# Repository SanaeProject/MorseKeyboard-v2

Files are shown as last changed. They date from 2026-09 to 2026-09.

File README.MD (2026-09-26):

# MorseKeyboard-V2

このリポジトリではモールス信号を用いて、キーボード入力、[LoRA](https://ja.wikipedia.org/wiki/LoRa)通信を行うことができるシステムを開発しています。

## 概要

- Bluetoothを用いたキーボード入力
- [LoRA](https://ja.wikipedia.org/wiki/LoRa)通信を用いた機器同士の通信

> [!WARNING]
> LoRA通信を行う場合は、[LoRA](https://ja.wikipedia.org/wiki/LoRa)の周波数帯域に注意してください。
> 日本では、920MHz帯を使用する必要があります。
> また、技適マークのないLoRAモジュールを使用する場合は、電波法違反となる可能性がありますので、注意してください。

### Bluetoothキーボード入力

モールス信号を用いて、Bluetoothキーボードとして動作することができます。  
これにより、モールス信号を入力することで、文字を打つことができます。

### LoRA通信

モールス信号を用いて、[LoRA](https://ja.wikipedia.org/wiki/LoRa)通信を行うことができます。
**このプロジェクトで作成した`E220`ヘッダは日本版のモジュールのみ対応しています。**

### 材料

- [ESP32C6](https://akizukidenshi.com/catalog/g/g129481/) 1100円
- [E220-900T22S](https://akizukidenshi.com/catalog/g/g131361/) (日本版) 1980円
- [ユニバーサル基板](https://akizukidenshi.com/catalog/g/g103229/) 130円
- [OLEDディスプレイ](https://www.amazon.co.jp/dp/B0GTV26DD2?ref=ppx_yo2ov_dt_b_fed_asin_title) 580円
- [800mAh Li-ionバッテリ](https://www.amazon.co.jp/dp/B0GTV26DD2?ref=ppx_yo2ov_dt_b_fed_asin_title) 990円
- アンテナ(920MHz) お好みでどおぞ

そのほか、ジャンパーワイヤやスイッチ、10kΩ抵抗、はんだ付け用の道具などが必要です。

### 配線

#### 表面

> [!NOTE]
> それぞれで配線を考えることをお勧めします。
> この配線では、Analogピンをすべて使用しているため、バッテリー電圧を測定できません。
> また、`esp32c6`の`GPIO 0`は、起動時にLOWにするとブートモードに入るため、LOWにしないように注意してください。

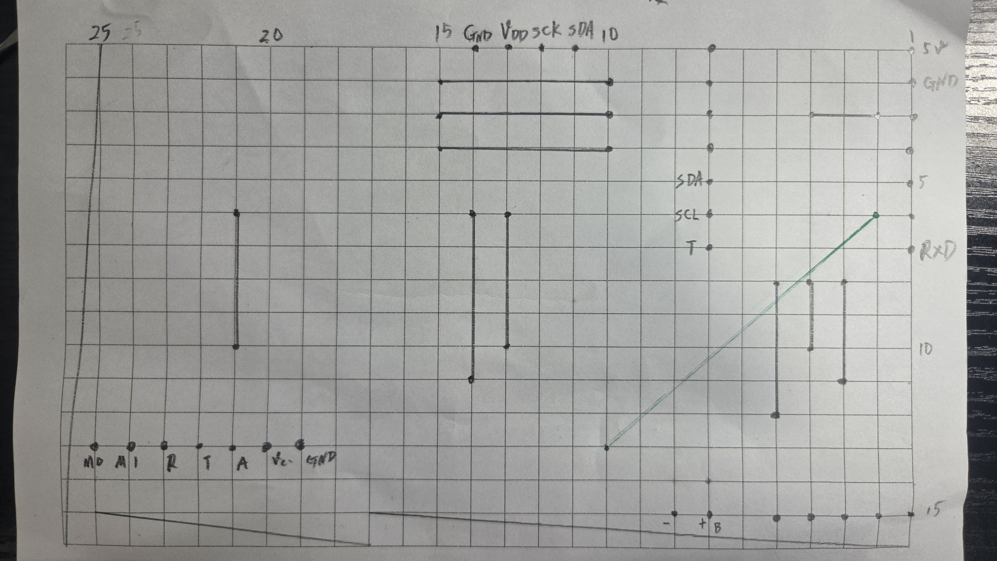
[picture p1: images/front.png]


### 裏面

> [!NOTE]
> 裏面の配線にて5vではなく3.3vを使用する必要があります。
> 5vを使用すると、バッテリー駆動時に5vが供給されず正常に動作しません。

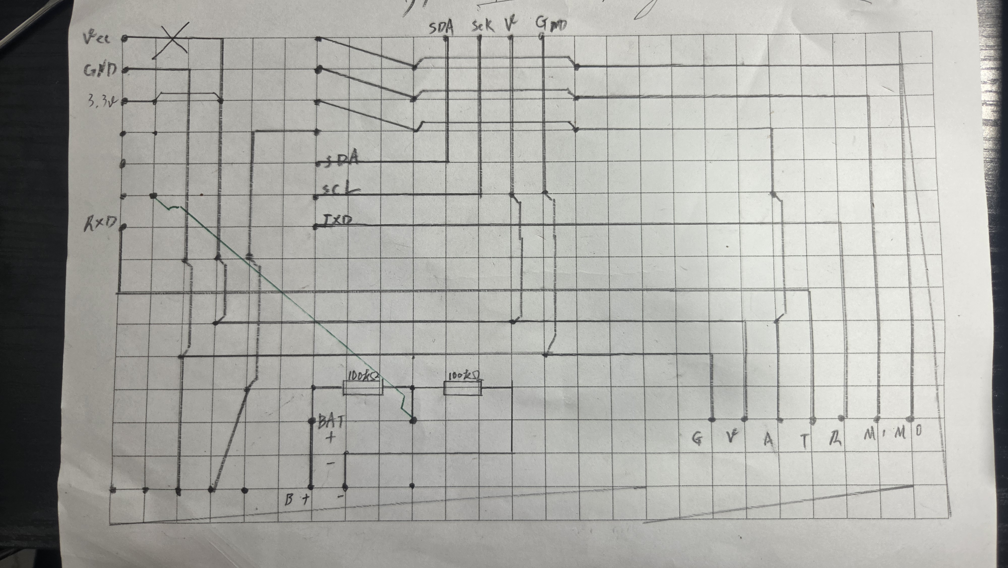
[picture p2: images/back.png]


### ケース

3Dプリンタでケースを作成することができます。  
STLファイルは[こちら](body.stl)にあります。

### 完成図

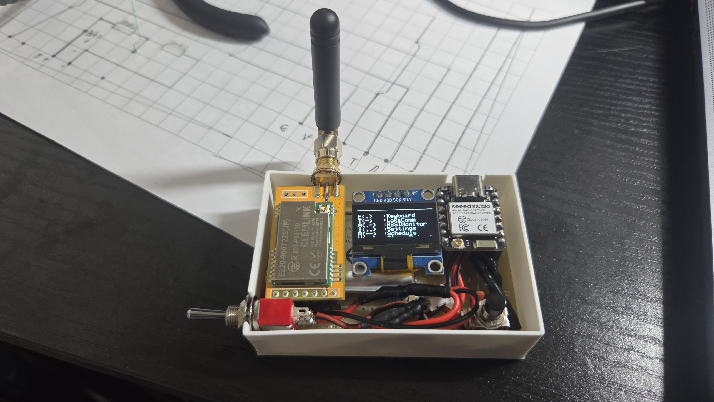
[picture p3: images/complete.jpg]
完成図


### 対応しているモールス信号

以下は、このシステムで対応しているモールス信号の一覧です。  
[Morse.hpp](include/Morse.hpp)に定義されているモールス信号を参照しています。

|文字|モールス信号|
|---|---|
|A|・－|
|B|ー・・・|
|C|－・－・|
|D|－・・|
|E|・|
|F|・・－・|
|G|－－・|
|H|・・・・|
|I|・・|
|J|・ーー|
|K|－・ー|
|L|・－・・|
|M|－－|
|N|－・|
|O|－－－|
|P|・－－・|
|Q|－－・ー|
|R|・－・|
|S|・・・|
|T|ー|
|U|・・ー|
|V|・・・ー|
|W|・－－|
|X|ー・・ー|
|Y|ー・ーー|
|Z|ーー・・|
|0|ーーーーー|
|1|・ーーーー|
|2|・・ーーー|
|3|・・・ーー|
|4|・・・・ー|
|5|・・・・・|
|6|ー・・・・|
|7|ーー・・・|
|8|ーーー・・|
|9|ーーーー・|
|\n|・・・ー・－|
|\e|・－・－・|
|\b|・・・・・・・・|

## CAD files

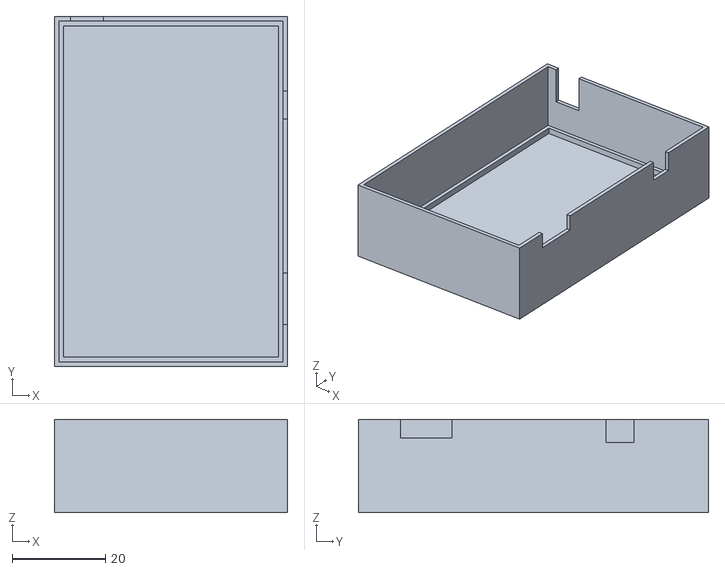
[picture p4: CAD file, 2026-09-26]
body.stl
50.0 x 75.0 x 20.0

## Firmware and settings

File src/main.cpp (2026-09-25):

#include <Arduino.h>
#include "Morse.hpp"
#include "OledDisplay.hpp"
#include "E220.hpp"
#include <Wire.h>
#include <Adafruit_GFX.h>
#include <Adafruit_SSD1306.h>
#include <HijelHID_BLEKeyboard.h>

#define ERROR(code) while(1){code; delay(1000);}
// I2C OLED display settings
#define OLED_RESET      -1
#define SCREEN_WIDTH    128
#define SCREEN_HEIGHT   64
#define LCD_I2C_ADDRESS 0x3c
#define I2C_SDA_PIN     22
#define I2C_SCL_PIN     23

// E220 module pin settings
#define M0_PIN   0
#define M1_PIN   1
#define AUX_PIN  2
#define TX_PIN   16
#define RX_PIN   17

// Morse
#define SIGNAL_PIN      21

// Battery
#define BATTERY_PIN     19

// 動作モード
enum class AppMode {
    MAIN_MENU,
    MORSE_KEYBOARD,
    LORA_COMMUNICATION,
    SETTINGS,
    RSSI_MONITOR,
    SCHEDULE,
};

//SECTION Global Variables
AppMode currentMode = AppMode::MAIN_MENU; // default

E220                  e220;
MorseSignalReader     morse;
HijelHID_BLEKeyboard  keyboard("MorseKeyboard", "SanaeProject", 100);
Adafruit_SSD1306      display(SCREEN_WIDTH, SCREEN_HEIGHT, &Wire, OLED_RESET);
OledDisplay           oledDisplay(display, 1, SSD1306Color::White, Align::Left);

// Settings
uint16_t tempAddress = 0;
uint8_t  tempChannel = 0;
uint16_t tempTargetAddress = 0;
uint16_t tempCryptKey = 0;

enum class SettingsItem {
    ADDRESS,
    CHANNEL,
    SEND_MODE,
    TARGET_ADDRESS,
    CRYPT_KEY
};

SettingsItem settingsItem = SettingsItem::ADDRESS;
String settingsInput = "";

// Lora
constexpr uint8_t MAX_MESSAGE_ROWS = 3;
uint8_t receivedMessageRow = 0;
uint8_t receivedMessageCol = 0;
String receivedMessage = "";

uint8_t sentMessageRow = 0;
uint8_t sentMessageCol = 0;
String sentMessage = "";

// RSSI Noise Monitor
constexpr size_t GRAPH_LENGTH = 5;
constexpr size_t GRAPH_REFRESH = 1000; // 1秒ごとに更新
int16_t noises[GRAPH_LENGTH];
size_t lastIdx = GRAPH_LENGTH-1;
Timer rssiTimer;

// Schedule
String scheduleMessage = "";
Timer scheduleTimer;
uint8_t scheduleCnt = 0;

//!SECTION

//SECTION プロトタイプ宣言
void mainMenu();          //ANCHOR - Main Menu
void loraCommunication(); //ANCHOR - LoRa Communication
void morseKeyboard();     //ANCHOR - Morse Keyboard
void rssiMonitor();       //ANCHOR - RSSI Noise Monitor
void settings();          //ANCHOR - Settings
void schedule();          //ANCHOR - Schedule
//!SECTION

//SECTION entry
//ANCHOR Setup
void setup(){
    // シリアル通信の初期化
    Serial.begin(115200);

    // キーボード初期化
    keyboard.begin();

    // ディスプレイの初期化
    if(display.begin(SSD1306_SWITCHCAPVCC, LCD_I2C_ADDRESS))
        Serial.println("SSD1306 allocated successfully!");
    else
        ERROR(Serial.println("SSD1306 allocation failed"));
    oledDisplay.init();
    oledDisplay.clear();

    // E220モジュールの初期化
    e220.setLogLevel(E220_LogLevel::INFO);
    if (!e220.begin(&Serial1, RX_PIN, TX_PIN, M0_PIN, M1_PIN, AUX_PIN, &Serial))
        ERROR(Serial.println("E220 begin failed"));
    if(!e220.readConfig())
        ERROR(Serial.println("E220 Failed to config read."));
    
    // 前回の引継ぎ
    tempAddress = e220.getDeviceAddress();
    tempChannel = e220.getFrequencyChannel();
    tempTargetAddress = tempAddress;
    tempCryptKey = e220.getCryptKey();

    const bool written = e220.setDeviceAddress(tempAddress)
        .setUARTSerialPortRate(E220_UARTSerialPortRate::RATE_9600)
        .setAirDataRate(E220_AirDataRate::BW125_1758BPS)
        .setPayloadLength(E220_PayloadLength::LENGTH_200)
        .setRSSINoiseEnable(true)
        .setTxPower(E220_TxPower_22S::POWER_13DBM)
        .setFrequencyChannel(tempChannel)
        .setRSSIByteEnable(false)
        .setSendMode(E220_SendMode::MODE_TRANSPARENT)
        .setWORCycle(E220_WORCycle::CYCLE_500MS)
        .setCryptKey(tempCryptKey)
        .writeConfig();
    if (!written)
        ERROR(Serial.println("E220 Failed to config write."));

    // Morse
    morse.begin(SIGNAL_PIN);

    // 完了画面
    Serial.println("===========Setup complete===========");
    oledDisplay.setTextSize(1);
    oledDisplay.setAlign(Align::Center)
        .clear()
        .setCursor(0, oledDisplay.getHeight() / 2)
        .println("Morse Keyboard v2")
        .setAlign(Align::Right)
        .println("by SanaeProject")
        .nextLine()
        .setAlign(Align::Left)
        .println("Author: SanaeProject")
        .println("Version: 1.0.0");
        
    delay(2000);
    oledDisplay.clear();
    pinMode(BATTERY_PIN, INPUT);
}

// ANCHOR Loop
bool isPressed = false;
void loop(){
    bool pressed = digitalRead(SIGNAL_PIN) == LOW;
    if(pressed && !isPressed){
        Serial.println("Button pressed");
        isPressed = true;
    } else if(!pressed && isPressed){
        Serial.println("Button released");
        isPressed = false;
    }

    switch(currentMode){
    case AppMode::MAIN_MENU:
        mainMenu();
        break;
    case AppMode::LORA_COMMUNICATION:
        loraCommunication();
        break;
    case AppMode::MORSE_KEYBOARD:
        morseKeyboard();
        break;
    case AppMode::RSSI_MONITOR:
        rssiMonitor();
        break;
    case AppMode::SETTINGS:
        settings();
        break;
    case AppMode::SCHEDULE:
        schedule();
        break;
    }

    delay(2);
}
//!SECTION

//SECTION pages
//ANCHOR - Main Menu
void mainMenu(){
    // setup
    oledDisplay.setTextSize(1)
        .setCursor(0, 0)
        .setAlign(Align::Center)
        .println("Morse Keyboard")
        .drawRect(0, oledDisplay.getCursorY(), oledDisplay.getWidth(), 1, SSD1306Color::White);

    // content
    oledDisplay.nextLine()
        .setAlign(Align::Left)
        .println("E(.)   :Keyboard")
        .println("T(-)   :LoRaComm")
        .println("A(.-)  :RSSIMonitor")
        .println("I(..)  :Settings")
        .println("M(--)  :Schedule")
        .println("N(-.)  :Clear Paired");

    char key = morse.getKey();
    AppMode previousMode = currentMode;
    switch(key){
    case 'e':
        currentMode = AppMode::MORSE_KEYBOARD;
        break;
    case 't':
        currentMode = AppMode::LORA_COMMUNICATION;
        break;
    case 'a':
        currentMode = AppMode::RSSI_MONITOR;
        break;
    case 'i':
        currentMode = AppMode::SETTINGS;
        break;
    case 'm':
        currentMode = AppMode::SCHEDULE;
        break;
    case 'n':
        keyboard.clearBonds();
        oledDisplay.clear()
            .setAlign(Align::Center)
            .setCursor(0, oledDisplay.getHeight() / 2 - BASE_CHAR_HEIGHT)
            .println("Cleared paired devices");
        delay(2000);
        oledDisplay.clear();

        currentMode = AppMode::MAIN_MENU;
        break;
    case MORSE_KEY_NONE:
        break;
    default:
        Serial.print("Invalid input: " + String(key));
        oledDisplay.setAlign(Align::Center)
            .clearLine()
            .print("Invalid input: " + String(key));

        break;
    }

    if(previousMode != currentMode)
        oledDisplay.clear();
}

// ANCHOR - LoRa Communication
void loraInsertBuffer(const char c, String& message, uint8_t& row, uint8_t& col){
    if(c == '\r') return; // 改行コードは無視

    message += c;
    col++;
    uint16_t width = (col + 1) * BASE_CHAR_WIDTH + oledDisplay.getPadding().left;
    bool isLineBreak = (c == '\n') || (width >= oledDisplay.getWidth());

    if(width >= oledDisplay.getWidth()){
        col = 0;
        message += '\n';
    }
    if(isLineBreak) row++;

    if(row >= MAX_MESSAGE_ROWS){ // 行数超過時に最古の1行を削除
        int firstNewline = message.indexOf('\n');
        if(firstNewline != -1)
            message = message.substring(firstNewline + 1);
        
        row--;
        oledDisplay.clear();
    }
}
void loraCommunication() {
    // 描画準備
    oledDisplay.setTextSize(1)
        .setCursor(0, 0);
    
    oledDisplay.setAlign(Align::Left)
        .println("Send:\n" + sentMessage)
        .setCursor(0, oledDisplay.getHeight() / 2)
        .fillRect(0, oledDisplay.getCursorY(), oledDisplay.getWidth(), oledDisplay.getHeight() / 2, SSD1306Color::Black)
        .drawRect(0, oledDisplay.getCursorY(), oledDisplay.getWidth(), 1, SSD1306Color::White)
        .println("Received:\n" + receivedMessage);
    oledDisplay.display();

    // 入力・送信処理
    char key = morse.getKey();
    if (key == '\e'){
        currentMode = AppMode::MAIN_MENU;
        oledDisplay.clear();
        return;
    }
    if (key != MORSE_KEY_NONE && key != '?') {
        Serial.print("Morse Key: ");
        Serial.println(key);

        if(e220.getSendMode() == E220_SendMode::MODE_TRANSPARENT)
            e220.send((uint8_t*)&key, 1);
        else
            e220.send((uint8_t*)&key, 1, tempTargetAddress,tempChannel);

        loraInsertBuffer(key, sentMessage, sentMessageRow, sentMessageCol);
    }

    // 受信データの処理
    while (e220.available()) {
        char c = e220.read();
        loraInsertBuffer(c, receivedMessage, receivedMessageRow, receivedMessageCol);
    }
}

//ANCHOR - Morse Keyboard
void morseKeyboard(){
    oledDisplay.setTextSize(1)
        .setCursor(0, 0)
        .setAlign(Align::Center)
        .println("Morse Keyboard")
        .drawRect(0, oledDisplay.getCursorY(), oledDisplay.getWidth(), 1, SSD1306Color::White)
        .nextLine();

    if(!keyboard.isConnected() || !keyboard.isPaired()){
        Serial.println("Keyboard is not connected.");
        oledDisplay.clearLine()
            .setAlign(Align::Left)
            .println("Keyboard is not connected.");
    }

    char key = morse.getKey();
    if(key == '\e'){
        currentMode = AppMode::MAIN_MENU;
        oledDisplay.clear();
        return;
    }
    if(key != MORSE_KEY_NONE){
        oledDisplay.clearLine()
            .setAlign(Align::Center)
            .println("Morse Key: " + String(key));
        keyboard.print(key);
    }
}

//ANCHOR - RSSI Monitor
size_t getFirstIdx(){
    return lastIdx+1 < GRAPH_LENGTH ? lastIdx+1 : 0;
}
size_t getNextIdx(size_t idx){
    return idx+1 < GRAPH_LENGTH ? idx+1 : 0;
}
void viewGraph(){
    const int16_t max = 0;
    const int16_t min = -110;
    const int16_t paddingX = BASE_CHAR_WIDTH * 4; // 4文字分パディング

    const int16_t x = paddingX,
    y      = oledDisplay.getHeight()/ 4,
    width  = oledDisplay.getWidth() - 2*paddingX,
    height = oledDisplay.getHeight()/ 4*3;
    
    // 初期化
    oledDisplay.setCursor(0, 0)
        .fillRect(x+1, y+1, width-2, height-2, SSD1306Color::Black);

    // 外枠
    oledDisplay.setCursor(0, y).print(String(min)) // 一番上
        .setCursor(0, y + height - BASE_CHAR_HEIGHT).print(String(max)) // 真ん中
        .setCursor(0, y+height/2 - BASE_CHAR_HEIGHT/2).print(String((max+min)/2)) // 一番下
        .drawLine(x, y+height/2, x+width, y+height/2)   // 真ん中線
        .setCursor(0, 0).drawRect(x, y, width, height); // 外枠

    const int16_t deltaGraphX = width / GRAPH_LENGTH;
    const int16_t circleRadius = 2;
    int16_t prevY = y + height/2 - (noises[lastIdx] - min) * height / (max - min);
    for(size_t cnt = 0, idx = getFirstIdx();cnt < GRAPH_LENGTH; cnt++, idx = getNextIdx(idx)){
        int16_t graphY = y + height/2 - (noises[idx] - min) * height / (max - min);
        int16_t graphX = x + cnt * deltaGraphX;

        graphY = constrain(graphY, y + circleRadius, y + height - circleRadius);
        oledDisplay.drawCircle(graphX, graphY, circleRadius);
        if(cnt > 0)
            oledDisplay.drawLine(x + (cnt-1) * deltaGraphX, prevY, graphX, graphY);
        prevY = graphY;
    }

    oledDisplay.display();
}
void rssiMonitor(){
    // エスケープ
    char key = morse.getKey();
    if(key == '\e'){
        currentMode = AppMode::MAIN_MENU;
        oledDisplay.clear();
    }

    // 1秒ごとに更新
    if(!rssiTimer.isRunning() || rssiTimer.elapsed() >= GRAPH_REFRESH){
        rssiTimer.start();
    }else
        return;

    oledDisplay.setTextSize(1)
        .setCursor(0, 0);

    int16_t rssi = e220.getRSSINoise();
    oledDisplay.clearLine()
        .setAlign(Align::Center)
        .println("RSSI: " + String(rssi) + " dBm");

    // 値を格納
    lastIdx = getFirstIdx();
    noises[lastIdx] = rssi;

    viewGraph();
}
//ANCHOR - Settings
//ANCHOR - Settings
void settings(){
    static SettingsItem item = SettingsItem::ADDRESS;
    static bool editing = false;
    static bool dirty = true; // 描画更新が必要かどうかのフラグ

    // --- 1. 入力処理 ---
    char key = morse.getKey();

    if(key != MORSE_KEY_NONE){
        dirty = true; // キー入力があったので画面を更新する

        // ESC (戻る / キャンセル)
        if(key == '\e'){
            if(editing){
                editing = false;
            }else{
                currentMode = AppMode::MAIN_MENU;
            }
            oledDisplay.clear();
            return;
        }

        // 編集中（値の変更）
        if(editing){
            switch(item){
            case SettingsItem::ADDRESS:
                if(key == 'e') { if(tempAddress < 0xFFFF) ++tempAddress; }
                else if(key == 't') { if(tempAddress > 0) --tempAddress; }
                break;

            case SettingsItem::CHANNEL:
                if(key == 'e') { if(tempChannel < 37) ++tempChannel; }
                else if(key == 't') { if(tempChannel > 0) --tempChannel; }
                break;

            case SettingsItem::SEND_MODE:
                if(key == 'e' || key == 't'){
                    if(e220.getSendMode() == E220_SendMode::MODE_TRANSPARENT)
                        e220.setSendMode(E220_SendMode::MODE_FIXED);
                    else
                        e220.setSendMode(E220_SendMode::MODE_TRANSPARENT);
                }
                break;

            case SettingsItem::TARGET_ADDRESS:
                if(key == 'e') { if(tempTargetAddress < 0xFFFF) ++tempTargetAddress; }
                else if(key == 't') { if(tempTargetAddress > 0) --tempTargetAddress; }
                break;

            case SettingsItem::CRYPT_KEY:
                if(key == 'e') { if(tempCryptKey < 0xFFFF) ++tempCryptKey; }
                else if(key == 't') { if(tempCryptKey > 0) --tempCryptKey; }
                break;
            }

            // Enter('\n')で決定
            if(key == '\n'){
                editing = false;
            }

            oledDisplay.clear();
        } 
        // 項目選択モード
        else {
            switch(key){
            case 'e': // (.) Address
                item = SettingsItem::ADDRESS;
                editing = true;
                break;

            case 't': // (-) Channel
                item = SettingsItem::CHANNEL;
                editing = true;
                break;

            case 'a': // (.-) SendMode
                item = SettingsItem::SEND_MODE;
                editing = true;
                break;

            case 'i': // (..) Target Address
                item = SettingsItem::TARGET_ADDRESS;
                editing = true;
                break;

            case 'm': // (--) Crypt Key
                item = SettingsItem::CRYPT_KEY;
                editing = true;
                break;

            case '\n': // 保存
                e220.setDeviceAddress(tempAddress)
                    .setFrequencyChannel(tempChannel)
                    .setCryptKey(tempCryptKey)
                    .writeConfig();

                oledDisplay.clear();
                break;
            }

            oledDisplay.clear();
        }
    }

    // --- 2. 描画処理（変化があった時だけ描画する） ---
    if(!dirty) return;
    dirty = false; // 描画処理を行うのでフラグを下げる

    oledDisplay.setTextSize(1)
        .setCursor(0, 0)
        .setAlign(Align::Center)
        .println("Settings")
        .drawRect(
            0,
            oledDisplay.getCursorY(),
            oledDisplay.getWidth(),
            1,
            SSD1306Color::White
        );

    oledDisplay.nextLine()
        .setAlign(Align::Left);

    if(!editing){
        oledDisplay.println("E(.)  : Address");
        oledDisplay.println("T(-)  : Channel");
        oledDisplay.println("A(.-) : SendMode");
        oledDisplay.println("I(..) : TargetAddr");
        oledDisplay.println("M(--) : CryptKey");
        oledDisplay.println("Enter : Save");
        oledDisplay.println("ESC   : Back");
    }else{
        switch(item){
        case SettingsItem::ADDRESS:
            oledDisplay.println("Address");
            oledDisplay.println("0x" + String(tempAddress, HEX));
            break;

        case SettingsItem::CHANNEL:
            oledDisplay.println("Channel");
            oledDisplay.println(String(tempChannel));
            break;

        case SettingsItem::SEND_MODE:
            oledDisplay.println("SendMode");
            oledDisplay.println(
                e220.getSendMode() == E220_SendMode::MODE_TRANSPARENT
                    ? "TRANSPARENT"
                    : "FIXED"
            );
            break;

        case SettingsItem::TARGET_ADDRESS:
            oledDisplay.println("Target Addr");
            oledDisplay.println("0x" + String(tempTargetAddress, HEX));
            break;

        case SettingsItem::CRYPT_KEY:
            oledDisplay.println("CryptKey");
            oledDisplay.println("0x" + String(tempCryptKey, HEX));
            break;
        }

        oledDisplay.println("")
            .println("E(.): UP / T(-): DOWN")
            .println("Enter: OK")
            .println("ESC: Cancel");
    }

    oledDisplay.display();
}

//ANCHOR - Schedule
void schedule() {
    oledDisplay
        .setTextSize(1)
        .setCursor(0, 0)
        .setAlign(Align::Center)
        .println("Schedule")
        .drawRect(0, oledDisplay.getCursorY(), oledDisplay.getWidth(), 1, SSD1306Color::White);

    // タイマースタート
    if (scheduleMessage.length() != 0 && !scheduleTimer.isRunning() && scheduleMessage.endsWith("\n"))
        scheduleTimer.start();

    // 送信
    if (scheduleMessage.length() != 0 && scheduleTimer.isRunning() && scheduleMessage.endsWith("\n") && scheduleTimer.elapsed() >= 5000) {

        scheduleTimer.start();
        String fullMessage = String(scheduleCnt) + "-" + scheduleMessage;

        if (e220.getSendMode() == E220_SendMode::MODE_TRANSPARENT)
            e220.send((uint8_t*)fullMessage.c_str(), fullMessage.length());
        else
            e220.send((uint8_t*)fullMessage.c_str(),fullMessage.length(),tempTargetAddress,tempChannel);

        oledDisplay.clear();
        oledDisplay
            .setTextSize(2)
            .setCursor(0, 16)
            .setAlign(Align::Center)
            .println("success!");

        oledDisplay
            .setTextSize(1)
            .setCursor(0, 42)
            .setAlign(Align::Center)
            .println(
                "Message " + String(scheduleCnt)
            );

        scheduleCnt++;

        return;
    }

    oledDisplay
        .nextLine()
        .setTextSize(1)
        .setAlign(Align::Left)
        .println("Message:");
    oledDisplay.println(scheduleMessage);

    // morse信号の入力
    char key = morse.getKey();
    if (key == '\e') {

        currentMode = AppMode::MAIN_MENU;

        oledDisplay.clear();
        scheduleTimer.stop();
        scheduleCnt = 0;
        scheduleMessage = "";

        return;
    }

    if (key != MORSE_KEY_NONE && key != '?') {

        oledDisplay
            .clearLine()
            .setAlign(Align::Center)
            .println("Morse Key: " + String(key));

        scheduleMessage += key;

        oledDisplay
            .println("Message: " + scheduleMessage);
    }
}
//!SECTION

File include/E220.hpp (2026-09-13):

/**
 * @note 参考文献: https://support.dragon-torch.tech/docs/lora/E220_ver.2.0/E220_ver.2.0_9
 */
#ifndef E220_HPP
#define E220_HPP

#include <Arduino.h>

//SECTION - 列挙型
//ANCHOR - モード
enum class E220_Mode : uint8_t {
    NORMAL = 0, // ノーマルモード
    CONFIG = 3  // コンフィグモード
};
//ANCHOR - コマンド
enum class E220_Command : uint8_t {
    WRITE_PERM = 0xC0, // 永続書き込み (EEPROM保存)
    READ       = 0xC1, // レジスタ読み出し
    ACK        = 0xC1, // E220からの応答ヘッダー
    WRITE_TEMP = 0xC2  // 一時書き込み (RAM保存)
};

//SECTION - REG0
//ANCHOR - UARTシリアル通信速度
enum class E220_UARTSerialPortRate : uint8_t {
    RATE_1200   = 0x00, // 000 1200bps
    RATE_2400   = 0x20, // 001 2400bps
    RATE_4800   = 0x40, // 010 4800bps
    RATE_9600   = 0x60, // 011 9600bps
    RATE_19200  = 0x80, // 100 19200bps
    RATE_38400  = 0xa0, // 101 38400bps
    RATE_57600  = 0xc0, // 110 57600bps
    RATE_115200 = 0xe0, // 111 115200bps
};
//ANCHOR - 空中通信速度
enum class E220_AirDataRate : uint8_t {
    // BW = 125kHz
    BW125_15625BPS = 0x00, // 00000 -> SF5,  15.625kbps
    BW125_9375BPS  = 0x04, // 00100 -> SF6,  9.375kbps
    BW125_5469BPS  = 0x08, // 01000 -> SF7,  5.469kbps
    BW125_3125BPS  = 0x0C, // 01100 -> SF8,  3.125kbps
    BW125_1758BPS  = 0x10, // 10000 -> SF9,  1.758kbps (Default)

    // BW = 250kHz
    BW250_31250BPS = 0x01, // 00001 -> SF5,  31.250kbps
    BW250_18750BPS = 0x05, // 00101 -> SF6,  18.750kbps
    BW250_10938BPS = 0x09, // 01001 -> SF7,  10.938kbps
    BW250_6250BPS  = 0x0D, // 01101 -> SF8,  6.250kbps
    BW250_3516BPS  = 0x11, // 10001 -> SF9,  3.516kbps
    BW250_1953BPS  = 0x15, // 10101 -> SF10, 1.953kbps

    // BW = 500kHz
    BW500_62500BPS = 0x02, // 00010 -> SF5,  62.500kbps
    BW500_37500BPS = 0x06, // 00110 -> SF6,  37.500kbps
    BW500_21875BPS = 0x0A, // 01010 -> SF7,  21.875kbps
    BW500_12500BPS = 0x0E, // 01110 -> SF8,  12.500kbps
    BW500_7031BPS  = 0x12, // 10012 -> SF9,  7.031kbps
    BW500_3906BPS  = 0x16, // 10110 -> SF10, 3.906kbps
    BW500_2148BPS  = 0x1A  // 11010 -> SF11, 2.148kbps
};
//!SECTION

//SECTION - REG1
//ANCHOR - ペイロード長
enum class E220_PayloadLength : uint8_t {
    LENGTH_200 = 0x00, // 00 200byte
    LENGTH_128 = 0x40, // 01 128byte
    LENGTH_64  = 0x80, // 10 64byte
    LENGTH_32  = 0xC0, // 11 32byte
};
//ANCHOR - 送信出力
enum class E220_TxPower_22S : uint8_t {
    NOT_AVAILABLE = 0x00,
    POWER_13DBM   = 0x01,
    POWER_7DBM_V1 = 0x02,
    POWER_0DBM    = 0x03,
    POWER_1DBM    = 0x04,
    POWER_2DBM    = 0x05,
    POWER_3DBM    = 0x06,
    POWER_4DBM    = 0x07,
    POWER_5DBM    = 0x08,
    POWER_6DBM    = 0x09,
    POWER_7DBM    = 0x0A,
    POWER_8DBM    = 0x0B,
    POWER_9DBM    = 0x0C,
    POWER_10DBM   = 0x0D,
    POWER_11DBM   = 0x0E,
    POWER_12DBM   = 0x0F
};
//!SECTION

//SECTION - REG3
//ANCHOR - 送信モード
enum class E220_SendMode : uint8_t {
    MODE_TRANSPARENT = 0x00,
    MODE_FIXED       = 0x40
};
//ANCHOR - WORサイクル
enum class E220_WORCycle : uint8_t {
    CYCLE_500MS  = 0x00,
    CYCLE_1000MS = 0x01,
    CYCLE_1500MS = 0x02,
    CYCLE_2000MS = 0x03,
    CYCLE_2500MS = 0x04,
    CYCLE_3000MS = 0x05,
};
//!SECTION
//!SECTION

// ANCHOR - ログレベル
enum class E220_LogLevel : uint8_t {
    NONE  = 0,
    ERROR = 1,
    WARN  = 2,
    INFO  = 3
};

//ANCHOR - 設定フォーマット
/**
 * @brief E220の設定フォーマット
 */
struct __attribute__((packed)) E220_ConfigFormat {
    E220_Command command;
    uint8_t registerAddress;
    uint8_t length;
    
    uint8_t ADDH;
    uint8_t ADDL;
    uint8_t REG0;
    uint8_t REG1;
    uint8_t REG2;
    uint8_t REG3;

    uint8_t CRYPT_H;
    uint8_t CRYPT_L;
};
//ANCHOR - 設定パケット
union E220_ConfigPacket {
    uint8_t bytes[11];
    E220_ConfigFormat format;
};

//ANCHOR - E220クラス
class E220 {
private:
    E220_ConfigPacket _config;
    Stream* _serial;
    Stream* _debug_serial;

    E220_LogLevel _logLevel = E220_LogLevel::NONE;

    int8_t _m0Pin;
    int8_t _m1Pin;
    int8_t _auxPin;

    bool _isAppliedConfig = false; // 設定が適用されたかどうかのフラグ

    /**
     * @brief モジュールの最大チャンネル数を取得する
     * @return 最大チャンネル数
     * @note データレートによって最大チャンネル数が変わる
     *  BW125kHzでは920.6～928.0MHz (200kHz間隔38波 CH:0～37)
     *  BW250kHzでは920.7～927.9MHz (200kHz間隔37波 CH:0～36)
     *  BW500kHzでは920.8～926.8MHz (200kHz間隔31波 CH:0～30)
     */
    inline uint8_t _getMaxChannel() const {
        _debug("E220 Info: Getting max channel based on air data rate", E220_LogLevel::INFO);

        uint8_t airDataRate = this->_config.format.REG0 & 0x1F;
        switch(static_cast<E220_AirDataRate>(airDataRate)) {
            case E220_AirDataRate::BW125_15625BPS:
            case E220_AirDataRate::BW125_9375BPS:
            case E220_AirDataRate::BW125_5469BPS:
            case E220_AirDataRate::BW125_3125BPS:
            case E220_AirDataRate::BW125_1758BPS:
                _debug("E220 Info: Air data rate is BW125kHz, max channel is 37", E220_LogLevel::INFO);
                return 37;
            case E220_AirDataRate::BW250_31250BPS:
            case E220_AirDataRate::BW250_18750BPS:
            case E220_AirDataRate::BW250_10938BPS:
            case E220_AirDataRate::BW250_6250BPS:
            case E220_AirDataRate::BW250_3516BPS:
            case E220_AirDataRate::BW250_1953BPS:
                _debug("E220 Info: Air data rate is BW250kHz, max channel is 36", E220_LogLevel::INFO);
                return 36;
            case E220_AirDataRate::BW500_62500BPS:
            case E220_AirDataRate::BW500_37500BPS:
            case E220_AirDataRate::BW500_21875BPS:
            case E220_AirDataRate::BW500_12500BPS:
            case E220_AirDataRate::BW500_7031BPS:
            case E220_AirDataRate::BW500_3906BPS:
            case E220_AirDataRate::BW500_2148BPS:
                _debug("E220 Info: Air data rate is BW500kHz, max channel is 30", E220_LogLevel::INFO);
                return 30;
        }

        _debug("E220 Error: Unknown air data rate, returning 0 as max channel", E220_LogLevel::ERROR);
        return 0;
    }

    /**
     * @brief AUXピンが待機状態になるまで待機する
     * @return AUXピンが待機状態になった場合はtrue、タイムアウトした場合はfalse
     * @note AUXピンが接続されていない場合は20ms待機する
     * @note AUXピンが接続されている場合は、AUXピンがHIGHになるまで待機する
     */
    inline bool _waitAUX() const {
        _debug("E220 Info: Waiting for AUX pin to go HIGH", E220_LogLevel::INFO);

        const uint32_t start = millis();
        if(_auxPin >= 0) {
            while(digitalRead(_auxPin) == LOW){
                if (millis() - start > this->timeout) {
                    _debug("E220 Error: Timeout waiting for AUX pin to go HIGH", E220_LogLevel::ERROR);
                    return false;
                }
                delay(1);
            }
        }else{
            delay(20);
        }

        _debug("E220 Info: AUX pin is HIGH", E220_LogLevel::INFO);
        return true;
    }
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

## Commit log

2026-09-02 初期設定ファイルとライブラリの追加、モールス信号リーダーの実装
2026-09-02 モールス信号入力の判定ロジックを改善し、長音信号の処理を追加
2026-09-02 モールス信号の最大長とダッシュ長、待機時間を修正し、対応表を整理
2026-09-04 HijelHID_BLEKeyboard.hを使用しBLEモールスキーボードを作成します。
2026-09-05 初期設定ファイル、ライブラリ、OLEDディスプレイの実装を追加し、モールス信号の入力処理を統合
2026-09-05 E220ヘッダーファイルを追加し、LoRa E220モジュールの設定と通信機能を実装
2026-09-07 E220モジュールの受信および送信機能を実装し、メインプログラムを更新
2026-09-08 E220モジュールの送信モードを透過モードに変更し、設定情報の出力を整理
2026-09-08 E220モジュールの送信モードを透過モードに変更し、送信関数の引数を簡略化
2026-09-09 E220モジュールのデバッグ機能を追加し、タイムアウト処理を強化
2026-09-09 E220モジュールの設定情報を出力するprintConfig関数を追加
2026-09-10 ノーマルモードに戻す際の成功判定を強化し、プラットフォーム設定を更新
2026-09-11 仮で正規のヘッダを追加します。
2026-09-11 E220モジュールにログレベルを追加し、エラーメッセージの出力を強化
2026-09-11 E220モジュールの設定を改善し、デバッグログを追加
2026-09-12 E220受信機の初期設定を追加し、構成情報の書き込み機能を実装
2026-09-12 E220モジュールの基本機能を実装し、設定およびデータ送信機能を追加
2026-09-12 E220モジュールの設定を更新し、送信機能を追加
2026-09-13 E220モジュールのデバッグログ機能を強化し、設定適用フラグを追加
2026-09-13 Refactor E220 library and main application
    - Removed obsolete E220 library header and firmware definitions.
    - Updated main application to integrate OLED display and BLE keyboard functionalities.
    - Introduced new application modes: Morse Keyboard, LoRa Communication, Settings, and RSSI Monitor.
    - Enhanced LoRa communication handling with improved message sending and receiving logic.
    - Added RSSI monitoring feature with graphical representation on OLED display.
    - Cleaned up pin assignments and initialization routines for better readability and maintainability.
2026-09-17 Refactor Morse Keyboard and LoRa Communication Code
    - Updated header file names for consistency (morse.hpp to Morse.hpp, Oled_Display.hpp to OledDisplay.hpp).
    - Increased Morse dash duration and end duration for better signal clarity.
    - Added new Morse code for escape character.
    - Introduced a main menu mode and refactored mode handling in the loop.
    - Enhanced OLED display management with a new OledDisplay class for better abstraction.
    - Improved error handling during setup and configuration of E220 module.
    - Streamlined the display update logic across different modes.
    - Added functionality to handle received messages in LoRa communication.
    - Implemented a graph view for RSSI monitoring with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
    [OledDisplay.hpp, main.cpp, morse.hpp]
2026-09-22 MorseKeyboardの設定機能を追加し、ボタン押下の状態管理を改善
2026-09-22 スケジュール機能を追加し、アプリケーションモードを更新
2026-09-25 モールス信号の判定機能を追加し、バッテリー入力ピンを設定。メインメニューにペアリング解除機能を追加。
2026-09-26 READMEを更新し、システムの概要、材料、配線図、モールス信号の一覧を追加。画像ファイルを新規追加。
2026-09-26 READMEとSTLファイルを更新し、配線図のパスを修正。3Dプリンタ用ケースの情報を追加。
    [body.stl]
2026-09-26 注意書きを追加
